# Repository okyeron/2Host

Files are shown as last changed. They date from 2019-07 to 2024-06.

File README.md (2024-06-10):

# 2host

2host (pronounced “Toast”) is a DIY USBMIDI host-to-host adapter.

2host uses 2 inexpensive microcontrollers to create a really short hardware MIDI bridge between two USBMIDI Host devices.

The first version of 2Host used [TeensyLC](https://www.pjrc.com/store/teensylc.html)’s. A new revised version uses two [Adafruit QtPy's](https://www.adafruit.com/qtpy) 

Here are a few examples of USBMIDI hosts which could be connected together:

hardware    
- norns 
- organelle 
- ansible 
- ipad (with Camera Connection kit) 
- raspberry pi (pisound, etc.) 
- any computer

software on any computer  
- ableton 
- orca  
- VCV Rack 
- etc. 

# QTPy version

SMD assembled PCBs are available [for sale in my shop](https://www.denki-oto.com/store/p67/qtpy2host.html#/). 

Requires two [Adafruit QtPy's](https://www.adafruit.com/qtpy) or [QtPy RP2040's](https://www.adafruit.com/product/4900).

Alternately you can use the [Seeeduino XIAO](https://www.seeedstudio.com/Seeeduino-XIAO-Arduino-Microcontroller-SAMD21-Cortex-M0+-p-4426.html) but this is not well tested.

### Firmware

Firmware is available as a pre-compiled UF2 file. 

To load the firmware, connect the QTPy to your computer and then double click the reset button on the QTPy to drop it into bootloader mode. This should now show you a QTPY_BOOT drive on your computer desktop. Drag the UF2 file to QTPY_BOOT and it should dismount/reboot and come back as the QT-2Host.

See the [firmware-qtpy directory](/firmware-qtpy) for the appropriate firmware.

# Teensy version 

[BOM](/hardware-teensy/BOM.md)

See the [firmware-teensy directory](/firmware-teensy/2host_firmware) for firmware

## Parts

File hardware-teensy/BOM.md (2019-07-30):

## 2host BOM

| Mouser  | QTY | Part | Value | Package |
|-----|:--:|-----|-----|-----|
|603-RC0805FR-07220RL|2|R3 R7|220R|0805|
|AC0805FR-0747RL|4|R1 R2 R5 R6|47R|0805|
|652-CR0805FX-4700ELF|2|R4 R8|470R|0805|
|80-C0805C104J5RACLR|2|C1 C2|100n|0805|
|833-1N4148W-TP|2|D1 D2|1N4148|SOD-123| 
|859-6N138S|2|OK1 OK2|6N138|SMD-8| 
||2| |TEENSY_LC||
|855-M20-9994045|1||male pin headers*||

[Mouser Cart](https://www.mouser.com/ProjectManager/ProjectDetail.aspx?AccessID=799423ce4a)

Order Teensy's from [PJRC here](https://www.pjrc.com/store/teensylc.html)

## Build notes

* pin headers can be whatever you have around. I get 1x40 headers in bulk from Tayda. Mouser has a 1x20 here [855-M20-9994045](https://www.mouser.com/ProductDetail/Harwin/M20-9994045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). Basically you need at least 2 1x3 headers to connect each of the Teensies. I also used a couple 1x2 headers as supports.
* Don't bother soldering pin headers to all the pins on the Teensies. You only need the last three pins on the USB connector end. (shown with white markings on the board)

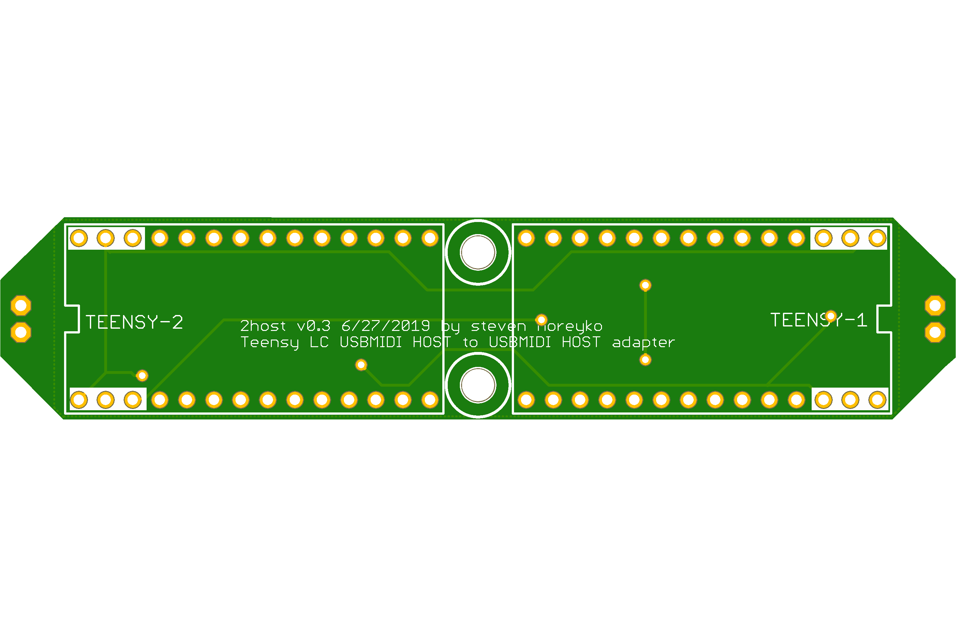
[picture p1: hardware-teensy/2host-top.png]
<2host-top>

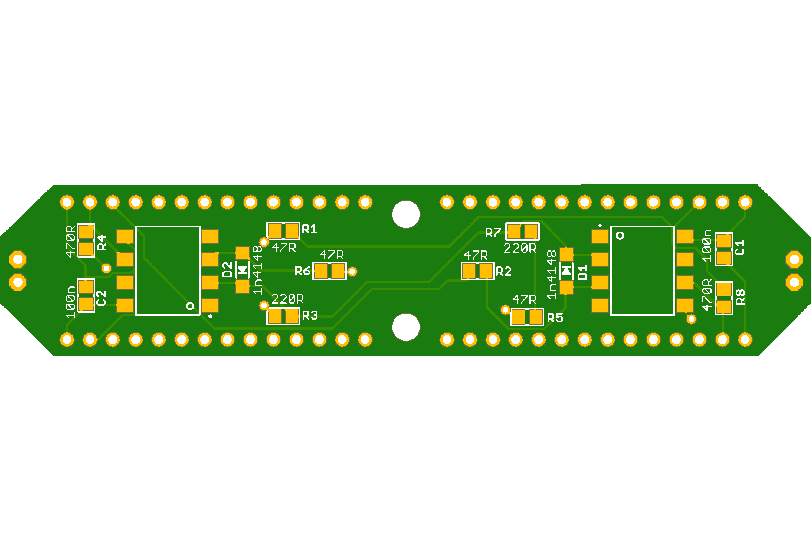
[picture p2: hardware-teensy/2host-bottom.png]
<2host-top>


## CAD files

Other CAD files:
hardware-teensy/2host_0.3.dxf

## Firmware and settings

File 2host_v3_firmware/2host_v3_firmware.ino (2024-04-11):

/*  
 *  2host-2040 - USBMIDI host-to-host adapter.
 *  steven noreyko - revised 2024 for RP2040 
 *  version 1.7
 *  
 *  Create a USBMIDI to HARDWARE MIDI interface.
 *  
 *  Select Raspberry Pi Pico (RP2040) from the "Tools > Board" menu
 *  Select Adafruit TinyUSB from the "Tools > USB Stack" menu
 *  
 */

#include <Arduino.h>
#include <Adafruit_TinyUSB.h>
#include <MIDI.h>
#include <elapsedMillis.h>

const int TXLED = 0;
const int RXLED = 1;
const int REDLED = 16; //  RED LED

Adafruit_USBD_MIDI usb_midi;

// Create the Serial and USB MIDI ports
MIDI_CREATE_INSTANCE(Adafruit_USBD_MIDI, usb_midi, USBMIDI);      // USBMIDI is USB MIDI
MIDI_CREATE_INSTANCE(HardwareSerial, Serial1, HWMIDI);           // HWMIDI is Hardware MIDI


// A variable to know how long the LED has been turned on
elapsedMillis ledOnMillis;

bool activity = false;

// DEVICE INFO FOR TinyUSB
char mfgstr[32] = "denki-oto";
char prodstr[32] = "2host-v3";

void setup() {
    USBDevice.setManufacturerDescriptor(mfgstr);
    USBDevice.setProductDescriptor(prodstr);

	pinMode(REDLED, OUTPUT);		// RED LED
	digitalWrite(REDLED, HIGH);		// Turn RED ON

    pinMode(TXLED, OUTPUT);
    pinMode(RXLED, INPUT);
    digitalWrite(TXLED, LOW);
    digitalWrite(RXLED, HIGH);
	  
    HWMIDI.begin(MIDI_CHANNEL_OMNI);
    USBMIDI.begin(MIDI_CHANNEL_OMNI);
    HWMIDI.turnThruOff();
    USBMIDI.turnThruOff();

    // wait until device mounted
    if (!TinyUSBDevice.mounted()){
    	delay(1000);
    }


   Serial.begin(115200);
//     Serial.println("MIDI Test");

}


void loop() {
    activity = false;
    
    int r=0, g=0, b=0;	// QTPy LED color for activity

    // READ HARDWARE MIDI
    if   (HWMIDI.read()) {
        // get a MIDI IN1 (Serial) message
        midi::MidiType type = HWMIDI.getType();
        byte channel = HWMIDI.getChannel();
        byte data1 = HWMIDI.getData1();
        byte data2 = HWMIDI.getData2();

        if (type == midi::Clock) {
            // no led activity on clock
//             Serial.println("clock");
            activity = false;
            // ledOnMillis = 0;
        } else {
//             Serial.println("read activity");
            r=0, g=100, b=0;
            activity = true;
        }

		// send the message to USB MIDI 
        if (type != midi::SystemExclusive) {
            // Normal messages, simply give the data to the USBMIDI.send()
            USBMIDI.send(type, data1, data2, channel);
//             Serial.println("usbmidi send");
        } else {
            // SysEx messages are special.  The message length is given in data1 & data2
            unsigned int SysExLength = data1 + data2 * 256;
            USBMIDI.sendSysEx(SysExLength, HWMIDI.getSysExArray(), true);
        }
    }

    // READ USBMIDI
    while(usb_midi.available()){
        if (USBMIDI.read()) {
            // get the USB MIDI message  (except SysEX)
            midi::MidiType type = USBMIDI.getType();
            byte channel = USBMIDI.getChannel();
            byte data1 = USBMIDI.getData1();
            byte data2 = USBMIDI.getData2();
 
            if (type == midi::Clock) {
                // no led activity on clock
                activity = false;
                // ledOnMillis = 0;
            } else {
                r=0, g=0, b=100;
                activity = true;
            }

            // send this message to Serial MIDI OUT
            if (type != midi::SystemExclusive) {
                // Normal messages, first we must convert USBMIDI's type (an ordinary
                // byte) to the MIDI library's special MidiType.
                midi::MidiType mtype = (midi::MidiType)type;

                // Then simply give the data to the MIDI library send()
                HWMIDI.send(mtype, data1, data2, channel);
            } else {
                // SysEx messages are special.  The message length is given in data1 & data2
                unsigned int SysExLength = data1 + data2 * 256;
                HWMIDI.sendSysEx(SysExLength, USBMIDI.getSysExArray(), true);
            }
        }
    }

    // blink the LED when any activity has happened
    if (activity) {
        // on
        // digitalWrite(LED_PIN, HIGH);
        ledOnMillis = 0;
    }
    if (ledOnMillis > 50 ) {
        // digitalWrite(LED_PIN, LOW);
        // clear
    }
}

// ***************************************************************************
// ** HELPERS                                                               **
// ***************************************************************************

// Pad a string of length 'len' with nulls
void pad_with_nulls(char* s, int len) {
    int l = strlen(s);
    for( int i=l;i<len; i++) {
        s[i] = '\0';
    }
}

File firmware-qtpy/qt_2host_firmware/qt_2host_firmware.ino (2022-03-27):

/*  
 *  QT-2host - USBMIDI host-to-host adapter.
 *  steven noreyko - revised 2022 
 *  version 1.5
 *  
 *  Create a USBMIDI to HARDWARE MIDI interface.
 *  
 *  Select QT PY (SAMD21) from the "Tools > Board > Adafruit SAMD (32 bits ARM Cortex...)" menu
 *  
 *  Select TinyUSB from the "Tools > USB Stack" menu
 *  
 */

#include <Arduino.h>
#include <Adafruit_TinyUSB.h>
#include <MIDI.h>
#include <Adafruit_NeoPixel.h> 
#include <elapsedMillis.h>

Adafruit_USBD_MIDI usb_midi;

// Create the Serial and USB MIDI ports
MIDI_CREATE_INSTANCE(HardwareSerial, Serial1, MIDI1);           // MIDI1 is Hardware MIDI
MIDI_CREATE_INSTANCE(Adafruit_USBD_MIDI, usb_midi, MIDI2);      // MIDI2 is USB MIDI

Adafruit_NeoPixel onePixel = Adafruit_NeoPixel(1, 11, NEO_GRB + NEO_KHZ800);

// A variable to know how long the LED has been turned on
elapsedMillis ledOnMillis;

bool activity = false;

// DEVICE INFO FOR ADAFRUIT M0 or M4 
char mfgstr[32] = "denki-oto";
char prodstr[32] = "QT-2host";

void setup() {
    USBDevice.setManufacturerDescriptor(mfgstr);
    USBDevice.setProductDescriptor(prodstr);
    
    MIDI1.begin(MIDI_CHANNEL_OMNI);
    MIDI2.begin(MIDI_CHANNEL_OMNI);
    MIDI1.turnThruOff();
    MIDI2.turnThruOff();

    Serial.begin(115200);

    // wait until device mounted
    while ( !USBDevice.mounted() ) delay(1);

    onePixel.begin();                           // Start the NeoPixel object
    onePixel.clear();                           // Set NeoPixel color to black (0,0,0)
    onePixel.setBrightness(50);     // Affects all subsequent settings

    onePixel.setPixelColor(0, 100, 0, 0);
    onePixel.show();
    delay(200);
    onePixel.clear();
    onePixel.show();                            // Update the pixel state

}


void loop() {
    activity = false;
    
    int r=0, g=0, b=100;	// QTPy LED color for activity

    // READ HARDWARE MIDI
    if (MIDI1.read()) {
        // get a MIDI IN1 (Serial) message
        midi::MidiType type = MIDI1.getType();
        byte channel = MIDI1.getChannel();
        byte data1 = MIDI1.getData1();
        byte data2 = MIDI1.getData2();

        if (type == midi::Clock) {
            // no led activity on clock
            //Serial.println("clock");
            activity = false;
            ledOnMillis = 0;
        } else {
            activity = true;
        }

		// send the message to USB MIDI 
        if (type != midi::SystemExclusive) {
            // Normal messages, simply give the data to the MIDI2.send()
            MIDI2.send(type, data1, data2, channel);
        } else {
            // SysEx messages are special.  The message length is given in data1 & data2
            unsigned int SysExLength = data1 + data2 * 256;
            
            //MIDI2.sendSysEx(SysExLength, MIDI.getSysExArray(), true, 0);
        }
    }

    // READ USBMIDI
    while(usb_midi.available()){
        if (MIDI2.read()) {
            // get the USB MIDI message  (except SysEX)
            midi::MidiType type = MIDI2.getType();
            byte channel = MIDI2.getChannel();
            byte data1 = MIDI2.getData1();
            byte data2 = MIDI2.getData2();
        
            if (type == midi::Clock) {
                // no led activity on clock
                activity = false;
                ledOnMillis = 0;
            } else {
                activity = true;
            }

            // send this message to Serial MIDI OUT
            if (type != midi::SystemExclusive) {
                // Normal messages, first we must convert MIDI2's type (an ordinary
                // byte) to the MIDI library's special MidiType.
                midi::MidiType mtype = (midi::MidiType)type;

                // Then simply give the data to the MIDI library send()
                MIDI1.send(mtype, data1, data2, channel);
            
            } else {
                // SysEx messages are special.  The message length is given in data1 & data2
                unsigned int SysExLength = data1 + data2 * 256;
                //MIDI1.sendSysEx(SysExLength, MIDI2.getSysExArray(), true);
            }
        }
    }

    // blink the LED when any activity has happened
    if (activity) {
        onePixel.setPixelColor(0, r, g, b);
        onePixel.show();
        ledOnMillis = 0;
    }
    if (ledOnMillis > 20 ) {
        onePixel.clear(); 
        onePixel.show();
    }
}

// ***************************************************************************
// ** HELPERS                                                               **
// ***************************************************************************

// Pad a string of length 'len' with nulls
void pad_with_nulls(char* s, int len) {
    int l = strlen(s);
    for( int i=l;i<len; i++) {
        s[i] = '\0';
    }
}

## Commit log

2019-07-30 updated bom
    [2host_0.3.dxf]
2019-12-24 add gerbers
2021-09-01 updates for qtpy_2host
    [2host_0.3.dxf]
2022-03-03 update directory names
    [2host_0.3.dxf]
2023-01-01 Update README.md
    fix teensy bom link
